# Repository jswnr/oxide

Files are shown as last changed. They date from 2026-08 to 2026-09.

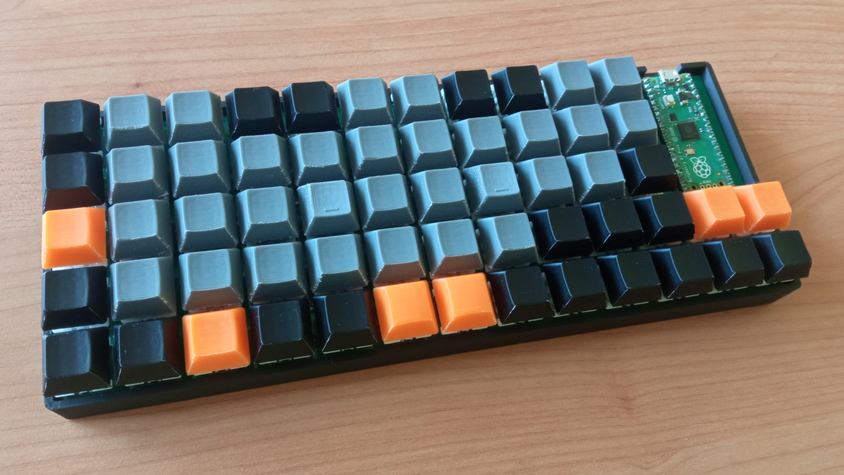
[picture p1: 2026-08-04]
images/keyboard.jpg

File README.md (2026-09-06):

# Oxide
A 60-key USB keyboard built with Raspberry Pi Pico

## Default layout
| | | | | | | | | | | | |
|---|---|---|---|---|---|---|---|---|---|---|---|
| \` | 1 F1 | 2 F2  | 3 F3 | 4 F4 | 5 F5  | 6 F6  | 7 F7  | 8 F8 | 9 F9 | 0 F10 | Backspace F11 |
| Tab | Q | W | E | R | T | Y | U | I | O | P | Delete F12 |
| Esc | A | S | D | F | G | H ← | J ↓ | K ↑  | L →  | ; | Enter |
| Shift | Z | X | C | V | B | N | M | , | . | / | ' |
| Control | Fn | Super | \\ | Alt  | Space | Space | AltGr | [ | ] | - | = |

## Bill of materials
| Component | Details | Quantity |
|---|---|---|
| PCB | 1.2 mm thick | 1 |
| Raspberry Pi Pico | | 1 |
| Male pin header | 2.54 mm pitch, 20 pins | 2 |
| Cherry MX switch | | 60 |
| 1N4148 diode | DO-35 package | 60 |
| Case | `case.scad` | 1 |
| Homing keycap | `keycap_homing.scad` | 2 |
| Space keycap | `keycap_space.scad` | 2 |
| Keycap | `keycap.scad` | 56 |
| M2 screw | Pan head, 6 mm long | 8 |
| M2 brass insert | 6 mm long, 3.5 mm outer diameter | 8 |

## Firmware
1. Install Pico SDK and Picotool.
2. Navigate to the `firmware` directory and run:
```
mkdir build
cd build
cmake ..
make -j$(nproc)
```
3. Hold down the BOOTSEL button on the Pico while plugging it in. Then run the following commands as root:
```
picotool load firmware.uf2
picotool reboot
```

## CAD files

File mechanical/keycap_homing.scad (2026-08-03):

/*
 * © 2026 Jakub Świniarski
 *
 * SPDX-License-Identifier: CERN-OHL-P-2.0
 */

include <keycap.scad>

bar_r = 0.3;
bar_l = 4;
bar_y = 2;

translate([0, -((cap_lt / 2) - bar_y), cap_h - curve_h])
    translate([0, 0, bar_r])
        rotate([0, 90, 0])
            cylinder(r = bar_r, h = bar_l, center = true);

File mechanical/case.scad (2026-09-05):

/*
 * © 2026 Jakub Świniarski
 *
 * SPDX-License-Identifier: CERN-OHL-P-2.0
 */

$fn = 100;
eps = 0.01;

pcb_l = 224.7;
pcb_w = 91.7;
pcb_t = 1.2;
pcb_m = 0.5;

extra_h = 6;
case_t = 2.5;

insulator_h = 2.54;
pico_h = 3.77;
pico_m = 2;
pico_bootsel_r = 1.5;

insert_d = 3.5;
boss_hole_undersize_d = 0.2;
boss_t = 2;

rod_r = 1.5;

gusset_l = 2;
gusset_t = 0.8;

usb_lt = 5.2;
usb_lb = 8;
usb_h = 3;
usb_wall_h = 1.7;
usb_m = 0.2;
usb_overhang = 1.3;
usb_recess_m = 3;

pico_tht_h = pico_h + insulator_h;

boss_hole_r = (insert_d - boss_hole_undersize_d) / 2;
boss_r = boss_hole_r + boss_t;
boss_h = pico_tht_h + pico_m;

rod_h = boss_h;

usb_slope_l = (usb_lb - usb_lt) / 2;

usb_poly = [
    [-usb_m, -usb_m],
    [usb_lb + usb_m, -usb_m],
    [usb_lb + usb_m, usb_wall_h + usb_m],
    [usb_lb - usb_slope_l + usb_m, usb_h + usb_m],
    [usb_slope_l - usb_m, usb_h + usb_m],
    [-usb_m, usb_wall_h + usb_m]
];

usb_recess_w = case_t - (usb_overhang - pcb_m);
usb_recess_r = (usb_h + (2 * usb_recess_m)) / 2;

// For (x, y) positions, the point (0, 0) is the bottom-left corner of the PCB.

pico_bootsel_x = 49.3;
pico_bootsel_y = 79.7;

usb_x = 42;
usb_z = case_t + boss_h - pico_tht_h;

boss_pos = [
    [17.35, 17.35],
    [74.35, 17.35],
    [150.35, 17.35],
    [207.35, 17.35],

    [17.35, 74.35],
    [74.35, 74.35],
    [150.35, 74.35],
    [207.35, 74.35]
];

rod_pos = [
    [112.35, 54],
    [112.35, 17.35],
];

module box() {
    minkowski() {
        cube([
            pcb_l + (2 * pcb_m),
            pcb_w + (2 * pcb_m),
            case_t + rod_h + pcb_t + extra_h - 1
        ]);
        cylinder(r = case_t, h = 1);
    }
}

module cavity() {
    translate([0, 0, case_t])
        cube([
            pcb_l + (2 * pcb_m),
            pcb_w + (2 * pcb_m),
            rod_h + pcb_t + extra_h + eps
        ]);

    translate([usb_x + pcb_m,
               pcb_w + (2 * pcb_m) - eps,
               usb_z])
        translate([0, case_t + (2 * eps), 0])
            rotate([90, 0, 0])
                linear_extrude(height = case_t + (2 * eps))
                    polygon(points = usb_poly);

    translate([usb_x + pcb_m,
               pcb_w + (2 * pcb_m) + case_t - usb_recess_w + eps,
               usb_z - usb_recess_m])
        union() {
            cube([usb_lb, usb_recess_w, usb_h + (2 * usb_recess_m)]);
            translate([0, usb_recess_w, usb_recess_r])
                rotate([90, 0, 0])
                    cylinder(r = usb_recess_r, usb_recess_w);
            translate([usb_lb, usb_recess_w, usb_recess_r])
                rotate([90, 0, 0])
                    cylinder(r = usb_recess_r, usb_recess_w);
        }


    translate([pico_bootsel_x + pcb_m, pico_bootsel_y + pcb_m, -eps])
        cylinder(r = pico_bootsel_r, h = (2 * eps) + case_t);
}

module gusset(rod_r, n) {
    rotate([0, 0, 45 + (n * 90)])
        union() {
            translate([(gusset_t / 2), rod_r, 0])
                rotate([0, -90, 0])
                    linear_extrude(height = gusset_t)
                        polygon(points = [
                            [0, 0],
                            [rod_h, 0],
                            [0, gusset_l]
                        ]);
            translate([-(gusset_t / 2), 0, 0])
                cube([gusset_t, rod_r, rod_h]);
        }
}

module boss(x, y) {
    translate([x, y, case_t])
        difference() {
            cylinder(r = boss_r, h = boss_h);
            translate([0, 0, eps])
                cylinder(r = boss_hole_r, h = boss_h);
        }
}

module rod(x, y) {
    translate([x, y, case_t])
        union() {
            cylinder(r = rod_r, h = rod_h);
            for (n = [0:3]) {
                gusset(rod_r, n);
            }
        }
}

translate([-(pcb_l / 2), -(pcb_w / 2), 0])
    union() {
        difference() {
            box();
            cavity();
        }
        for (r = boss_pos) {
            boss(r[0] + pcb_m, r[1] + pcb_m);
        }
        for (r = rod_pos) {
            rod(r[0] + pcb_m, r[1] + pcb_m);
        }
    }

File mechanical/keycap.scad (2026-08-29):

/*
 * © 2026 Jakub Świniarski
 *
 * SPDX-License-Identifier: CERN-OHL-P-2.0
 */

include <keycap_common.scad>

union() {
    difference() {
        difference() {
            minkowski() {
                frustum(cavity_lb, cavity_lt, cap_h);
                hemisphere(cap_t);
            }
            translate([0, 0, curve_r + cap_h - curve_h])
                sphere(r = curve_r);
        }
        translate([0, 0, -eps])
            frustum(cavity_lb, cavity_lt, rod_h);
    }
    interior();
}

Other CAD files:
mechanical/keycap_common.scad
mechanical/keycap_space.scad

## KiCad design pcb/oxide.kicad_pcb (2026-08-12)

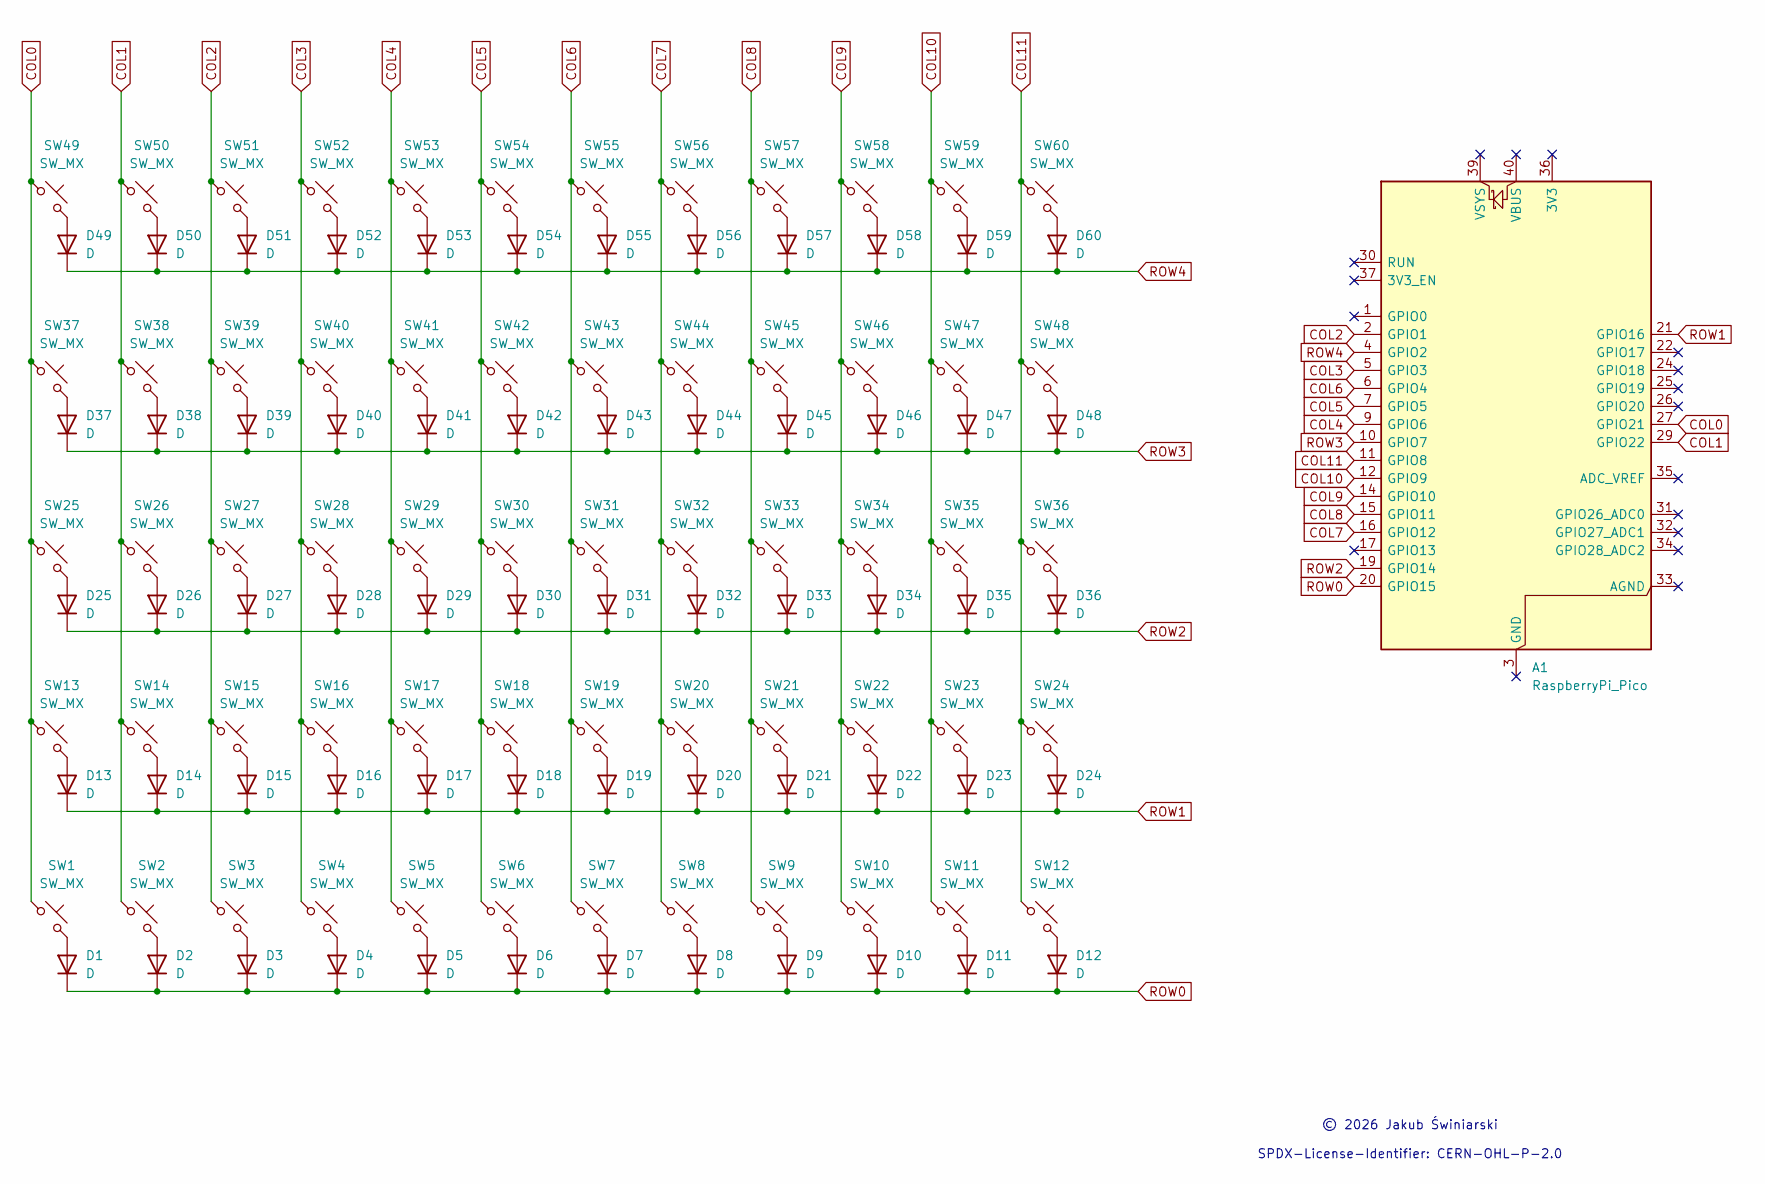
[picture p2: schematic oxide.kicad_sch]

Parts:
A1: RaspberryPi_Pico; RaspberryPi_Pico_Common_THT
D1, D2, D3, D4, D5, D6, D7, D8, D9, D10, D11, D12, D13, D14, D15, D16, D17, D18, D19, D20, D21, D22, D23, D24, D25, D26, D27, D28, D29, D30, D31, D32, D33, D34, D35, D36, D37, D38, D39, D40, D41, D42, D43, D44, D45, D46, D47, D48, D49, D50, D51, D52, D53, D54, D55, D56, D57, D58, D59, D60: D; D_DO-35_SOD27_P7.62mm_Horizontal
SW1, SW2, SW3, SW4, SW5, SW6, SW7, SW8, SW9, SW10, SW11, SW12, SW13, SW14, SW15, SW16, SW17, SW18, SW19, SW20, SW21, SW22, SW23, SW24, SW25, SW26, SW27, SW28, SW29, SW30, SW31, SW32, SW33, SW34, SW35, SW36, SW37, SW38, SW39, SW40, SW41, SW42, SW43, SW44, SW45, SW46, SW47, SW48, SW49, SW50, SW51, SW52, SW53, SW54, SW55, SW56, SW57, SW58, SW59, SW60: SW_MX; SW_Cherry_MX_1.00u_PCB

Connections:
COL0: A1.27 (GPIO21), SW1.1, SW13.1, SW25.1, SW37.1, SW49.1
COL1: A1.29 (GPIO22), SW2.1, SW14.1, SW26.1, SW38.1, SW50.1
COL2: A1.2 (GPIO1), SW3.1, SW15.1, SW27.1, SW39.1, SW51.1
COL3: A1.5 (GPIO3), SW4.1, SW16.1, SW28.1, SW40.1, SW52.1
COL4: A1.9 (GPIO6), SW5.1, SW17.1, SW29.1, SW41.1, SW53.1
COL5: A1.7 (GPIO5), SW6.1, SW18.1, SW30.1, SW42.1, SW54.1
COL6: A1.6 (GPIO4), SW7.1, SW19.1, SW31.1, SW43.1, SW55.1
COL7: A1.16 (GPIO12), SW8.1, SW20.1, SW32.1, SW44.1, SW56.1
COL8: A1.15 (GPIO11), SW9.1, SW21.1, SW33.1, SW45.1, SW57.1
COL9: A1.14 (GPIO10), SW10.1, SW22.1, SW34.1, SW46.1, SW58.1
COL10: A1.12 (GPIO9), SW11.1, SW23.1, SW35.1, SW47.1, SW59.1
COL11: A1.11 (GPIO8), SW12.1, SW24.1, SW36.1, SW48.1, SW60.1
unnamed: D1.2 (A), SW1.2
unnamed: D2.2 (A), SW2.2
unnamed: D3.2 (A), SW3.2
unnamed: D4.2 (A), SW4.2
unnamed: D5.2 (A), SW5.2
unnamed: D6.2 (A), SW6.2
unnamed: D7.2 (A), SW7.2
unnamed: D8.2 (A), SW8.2
unnamed: D9.2 (A), SW9.2
unnamed: D10.2 (A), SW10.2
unnamed: D11.2 (A), SW11.2
unnamed: D12.2 (A), SW12.2
unnamed: D13.2 (A), SW13.2
unnamed: D14.2 (A), SW14.2
unnamed: D15.2 (A), SW15.2
unnamed: D16.2 (A), SW16.2
unnamed: D17.2 (A), SW17.2
unnamed: D18.2 (A), SW18.2
unnamed: D19.2 (A), SW19.2
unnamed: D20.2 (A), SW20.2
unnamed: D21.2 (A), SW21.2
unnamed: D22.2 (A), SW22.2
unnamed: D23.2 (A), SW23.2
unnamed: D24.2 (A), SW24.2
unnamed: D25.2 (A), SW25.2
unnamed: D26.2 (A), SW26.2
unnamed: D27.2 (A), SW27.2
unnamed: D28.2 (A), SW28.2
unnamed: D29.2 (A), SW29.2
unnamed: D30.2 (A), SW30.2
unnamed: D31.2 (A), SW31.2
unnamed: D32.2 (A), SW32.2
unnamed: D33.2 (A), SW33.2
unnamed: D34.2 (A), SW34.2
unnamed: D35.2 (A), SW35.2
unnamed: D36.2 (A), SW36.2
unnamed: D37.2 (A), SW37.2
unnamed: D38.2 (A), SW38.2
unnamed: D39.2 (A), SW39.2
unnamed: D40.2 (A), SW40.2
unnamed: D41.2 (A), SW41.2
unnamed: D42.2 (A), SW42.2
unnamed: D43.2 (A), SW43.2
unnamed: D44.2 (A), SW44.2
unnamed: D45.2 (A), SW45.2
unnamed: D46.2 (A), SW46.2
unnamed: D47.2 (A), SW47.2
unnamed: D48.2 (A), SW48.2
unnamed: D49.2 (A), SW49.2
unnamed: D50.2 (A), SW50.2
unnamed: D51.2 (A), SW51.2
unnamed: D52.2 (A), SW52.2
unnamed: D53.2 (A), SW53.2
unnamed: D54.2 (A), SW54.2
unnamed: D55.2 (A), SW55.2
unnamed: D56.2 (A), SW56.2
unnamed: D57.2 (A), SW57.2
unnamed: D58.2 (A), SW58.2
unnamed: D59.2 (A), SW59.2
unnamed: D60.2 (A), SW60.2
ROW0: A1.20 (GPIO15), D1.1 (K), D2.1 (K), D3.1 (K), D4.1 (K), D5.1 (K), D6.1 (K), D7.1 (K), D8.1 (K), D9.1 (K), D10.1 (K), D11.1 (K), D12.1 (K)
ROW1: A1.21 (GPIO16), D13.1 (K), D14.1 (K), D15.1 (K), D16.1 (K), D17.1 (K), D18.1 (K), D19.1 (K), D20.1 (K), D21.1 (K), D22.1 (K), D23.1 (K), D24.1 (K)
ROW2: A1.19 (GPIO14), D25.1 (K), D26.1 (K), D27.1 (K), D28.1 (K), D29.1 (K), D30.1 (K), D31.1 (K), D32.1 (K), D33.1 (K), D34.1 (K), D35.1 (K), D36.1 (K)
ROW3: A1.10 (GPIO7), D37.1 (K), D38.1 (K), D39.1 (K), D40.1 (K), D41.1 (K), D42.1 (K), D43.1 (K), D44.1 (K), D45.1 (K), D46.1 (K), D47.1 (K), D48.1 (K)
ROW4: A1.4 (GPIO2), D49.1 (K), D50.1 (K), D51.1 (K), D52.1 (K), D53.1 (K), D54.1 (K), D55.1 (K), D56.1 (K), D57.1 (K), D58.1 (K), D59.1 (K), D60.1 (K)

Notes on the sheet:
© 2026 Jakub Świniarski SPDX-License-Identifier: CERN-OHL-P-2.0

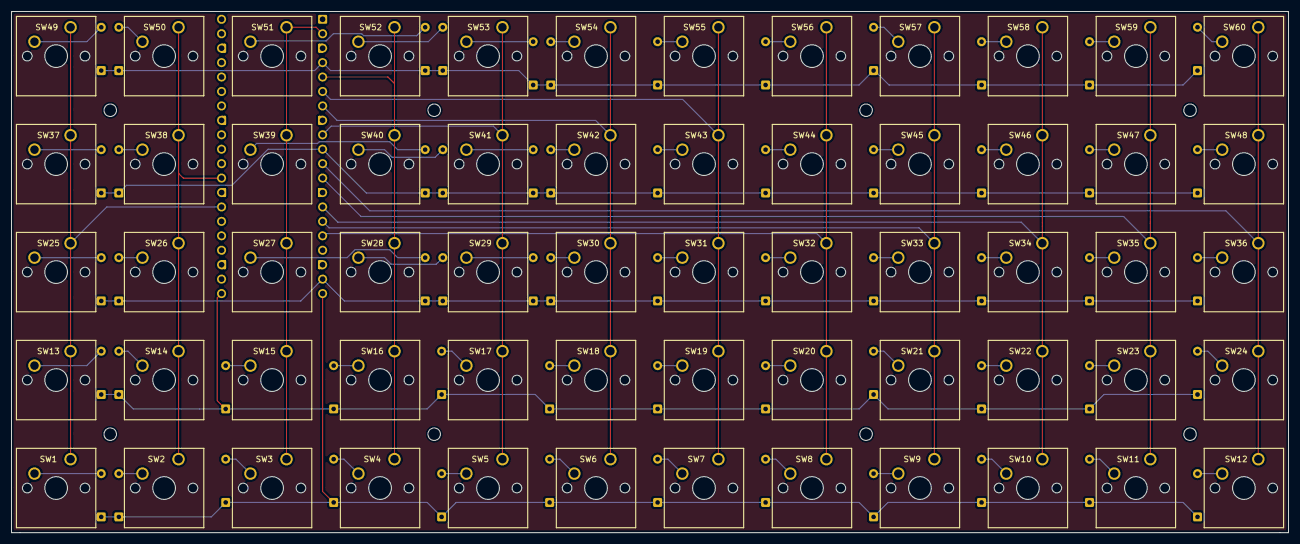
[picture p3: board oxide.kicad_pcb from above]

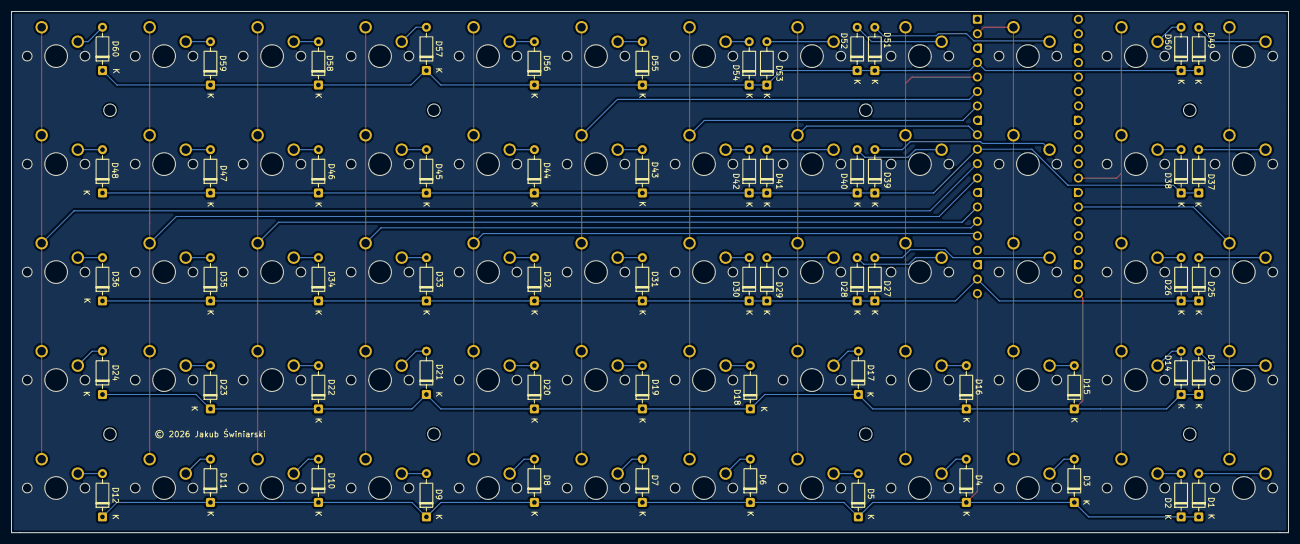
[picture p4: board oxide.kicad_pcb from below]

Board: 2 copper layers, 224.7 x 91.7 mm, 121 parts (61 on the bottom side), 77 nets.

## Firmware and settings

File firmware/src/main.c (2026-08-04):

/*
 * © 2026 Jakub Świniarski
 *
 * SPDX-License-Identifier: MIT
 */

#include <bsp/board_api.h>
#include <hardware/clocks.h>
#include <hardware/pll.h>
#include <hardware/vreg.h>
#include <pico/time.h>

#include "kbd.h"

static const uint32_t interval_ms = 10;

static uint8_t keycodes[N_KEYCODES] = { 0 };

int main(void) {
    board_init();

    tusb_rhport_init_t dev_init = {
        .role = TUSB_ROLE_DEVICE,
        .speed = TUSB_SPEED_FULL
    };
    tusb_init(BOARD_TUD_RHPORT, &dev_init);

    board_init_after_tusb();

    clock_stop(clk_adc);
    clock_stop(clk_rtc);
    clock_stop(clk_peri);

    clock_configure(
        clk_sys,
        CLOCKS_CLK_SYS_CTRL_SRC_VALUE_CLKSRC_CLK_SYS_AUX,
        CLOCKS_CLK_SYS_CTRL_AUXSRC_VALUE_CLKSRC_PLL_USB,
        48 * MHZ,
        48 * MHZ
    );
    pll_deinit(pll_sys);

    vreg_set_voltage(VREG_VOLTAGE_0_90);

    kbd_init();

    absolute_time_t next_scan = get_absolute_time();
    bool report_pending = false;
    while (true) {
        tud_task();

        if (time_reached(next_scan)) {
            next_scan = make_timeout_time_ms(interval_ms);

            if (kbd_scan(keycodes))
                report_pending = true;
        }

        if (report_pending && tud_hid_ready()) {
            tud_hid_keyboard_report(0, 0, keycodes);
            report_pending = false;
        }
    }
}

void tud_suspend_cb(bool remote_wakeup_en) {}

void tud_resume_cb(void) {}

uint16_t tud_hid_get_report_cb(uint8_t instance, uint8_t report_id, hid_report_type_t report_type, uint8_t *buffer, uint16_t reqlen) {}
void tud_hid_set_report_cb(uint8_t instance, uint8_t report_id, hid_report_type_t report_type, uint8_t const *buffer, uint16_t bufsize) {}

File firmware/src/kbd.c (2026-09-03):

/*
 * © 2026 Jakub Świniarski
 *
 * SPDX-License-Identifier: MIT
 */

#include <hardware/gpio.h>
#include <pico/time.h>

#include "kbd.h"
#include "layout.h"

static const uint8_t col_to_gpio[N_COLS] = { 21, 22, 1, 3, 6, 5, 4, 12, 11, 10, 9, 8 };
static const uint8_t row_to_gpio[N_ROWS] = { 15, 16, 14, 7, 2 };

static uint64_t row_settle_us = 5;

static bool send_empty = true;

void kbd_init(void) {
    for (size_t i = 0; i < N_COLS; i++) {
        gpio_init(col_to_gpio[i]);
        gpio_set_dir(col_to_gpio[i], GPIO_IN);
        gpio_pull_up(col_to_gpio[i]);
    }
    
    for (size_t i = 0; i < N_ROWS; i++) {
        gpio_init(row_to_gpio[i]);
        gpio_set_dir(row_to_gpio[i], GPIO_OUT);
        gpio_put(row_to_gpio[i], 1);
    }
}

bool kbd_scan(uint8_t *keycodes) {
    for (size_t i = 0; i < N_KEYCODES; i++)
        keycodes[i] = 0;

    const uint8_t (*cur_layout)[N_ROWS][N_COLS] = &layout;

    gpio_put(row_to_gpio[fn_row], 0);
    sleep_us(row_settle_us);

    if (gpio_get(col_to_gpio[fn_col]) == 0)
        cur_layout = &layout_fn;

    gpio_put(row_to_gpio[fn_row], 1);

    uint8_t index = 0;
    bool key_pressed = false;
    for (size_t i = 0; i < N_ROWS; i++) {
        if (index >= N_KEYCODES)
            break;

        gpio_put(row_to_gpio[i], 0);
        sleep_us(row_settle_us);

        for (size_t j = 0; j < N_COLS; j++) {
            if (gpio_get(col_to_gpio[j]) != 0)
                continue;

            keycodes[index] = (*cur_layout)[i][j];
            key_pressed = true;
            index++;
            if (index >= N_KEYCODES) {
                gpio_put(row_to_gpio[i], 1);
                break;
            }
        } 

        gpio_put(row_to_gpio[i], 1);
    }

    bool send = key_pressed || send_empty;
    send_empty = key_pressed;

    return send;
}

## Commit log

2026-08-03 Add KiCad project files
    [keyboard.kicad_pcb, keyboard.kicad_sch]
2026-08-03 Add OpenSCAD scripts
    [case.scad, keycap.scad, keycap_common.scad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]
2026-08-11 Update product name
    [keyboard.kicad_pcb]
2026-08-11 Update schematic and redesign PCB
    [keyboard.kicad_pcb, keyboard.kicad_sch]
2026-08-11 Add copyright notice
    [keyboard.kicad_pcb]
2026-08-12 Update .gitignore and mark unconnected pin in schematic
    [keyboard.kicad_pcb, keyboard.kicad_sch]
2026-08-12 Reroute trace
    [keyboard.kicad_pcb]
2026-08-12 Rename directories and files
    [case.scad, keycap.scad, keycap_common.scad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]
2026-08-12 Move Pico closer to the PCB edge and reroute traces
    [oxide.kicad_pcb, oxide.kicad_sch]
2026-08-12 Fix diode position
    [oxide.kicad_pcb]
2026-08-22 Organize variables and update boss and rod positions
    [case.scad, keycap_common.scad]
2026-08-29 Define epsilon and create cutouts for USB and BOOTSEL
    [case.scad, keycap.scad, keycap_common.scad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]
2026-09-03 Update pin numbers and layout
2026-09-04 USB recess
    [case.scad]
2026-09-05 Remove colliding supports, update Pico height
    [case.scad]
2026-09-05 Remove filament and solder from BOM
2026-09-06 Add mechanical parts to BOM
2026-09-06 Remove USB cable from BOM
